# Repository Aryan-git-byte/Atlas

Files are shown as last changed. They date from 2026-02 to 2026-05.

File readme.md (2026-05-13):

# Atlas DevBoard
# Overview:
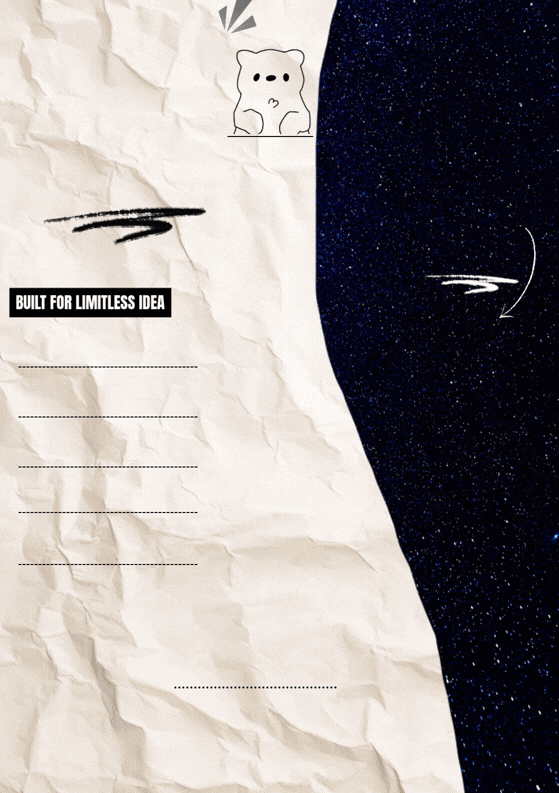
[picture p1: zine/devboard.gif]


## about the Board:
It is one of those perfect devboard i need for my projects, especically my IoTs one, and i was pretty tired of conecting different modules together, wiring em and all, SO i thought that why cant i make a board that fulfills my need, and this may even come handy for many other hackers/dev too. 
This board comprises of inbuilt BMS, GSM, GPRS, GPS, RS485 communication, mic, speaker, sd slots etc
with the main brain being esp32 s3 and A9G for gps/gprs/gsm.
## Application:
lots of IoT projects u can think of
plus normal projects too that needs lot of flash or eeprom

## How to use it:
Its pretty simple, you can just upload the code in firmawre/ through the usb connector or power it through the jst, and just upload code , interact with other modules as describe in schematic and BOOM ur powerful devboard workingggg., 
some serial cmds to test the board:

`help or ?` - show command menu   
`status` - show system info   
`reboot` - restart system   
`sd.ls` - list files  
`sd.cat` <filename> - read file   
`sd.rm` <filename> - delete file  
`gsm.at` <command> - send AT command  
`gsm.rssi` - signal strength  
`gsm.sms` <number> <message> - send SMS   
`gps.on` - enable GPS   
`gps.off` - disable GPS   
`gps.loc` - get GPS location  
`485.tx` <message> - send data    
`pin.set` <pin> <0|1> - set pin state   
`pin.get` <pin> - read pin state  
`pwr.sleep` <seconds> - light sleep   
`pwr.vbat` - read battery voltage 

# Schematic Overview:
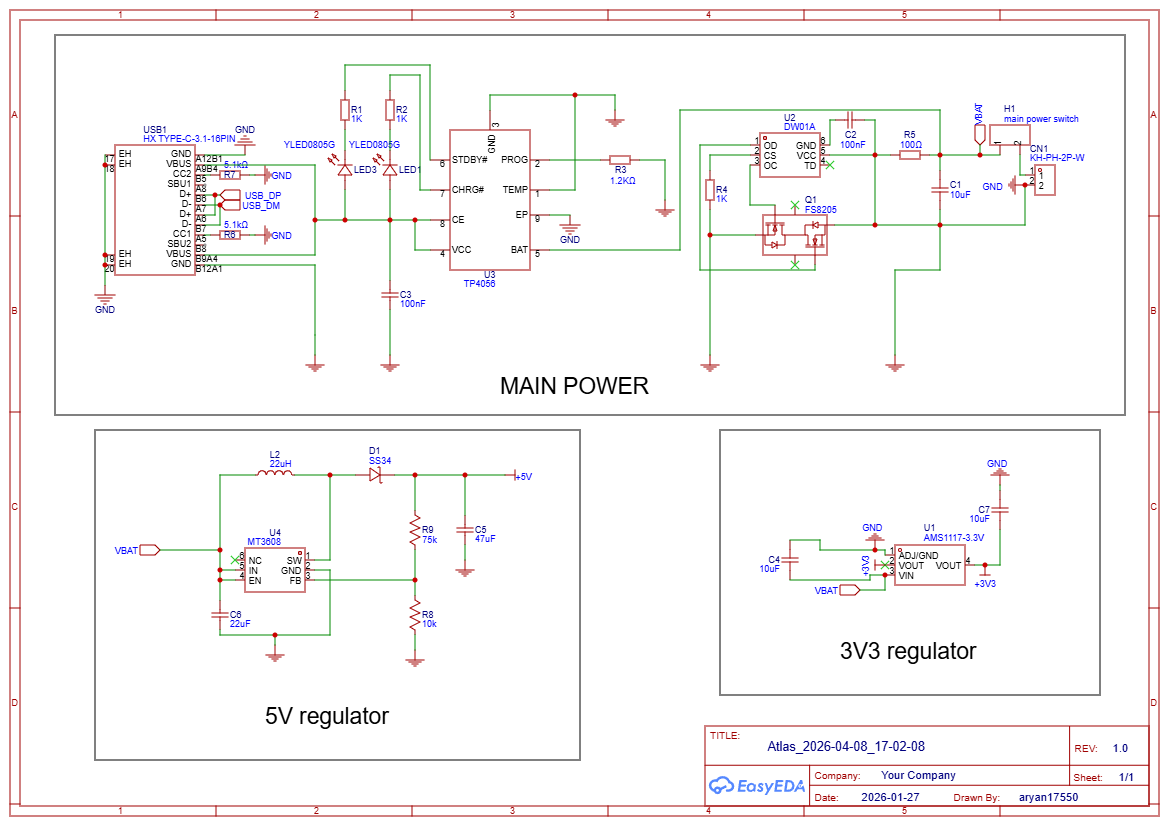
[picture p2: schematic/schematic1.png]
schematic-1

This page contains the whole power system of the board starting off we have the usb-C connector for both charging and coding, then we have BMS, a 5v Boost converter and a 3v3 linear regulator

after that we have, 
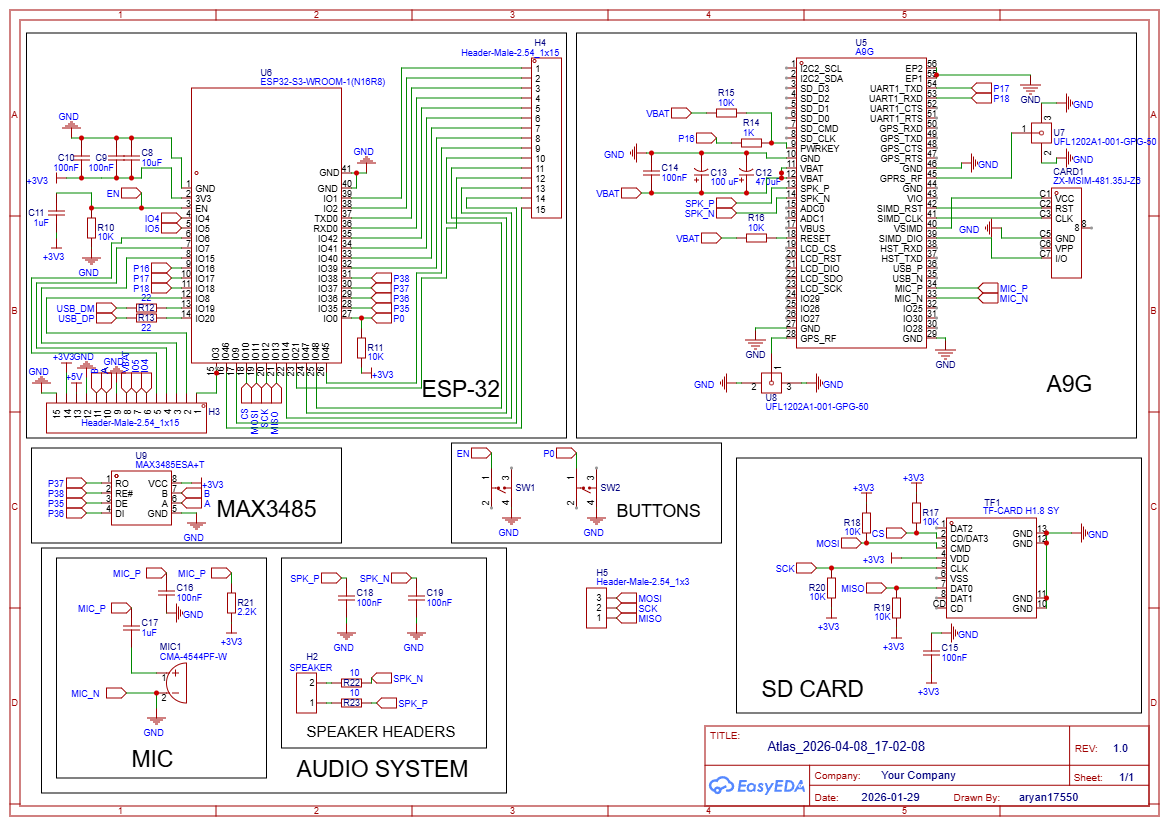
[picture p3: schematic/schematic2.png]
schematic-2

this page does the heavy work, with the first u can see the esp32-block along with its peripherals and the breakout connectors. after that we have A9G with its peripherals . and so with the max3485, buttons, jumpers, sd card, mic , speakers etc
# PCB overview:
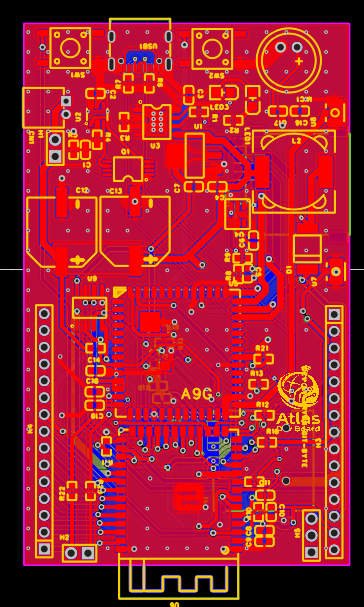
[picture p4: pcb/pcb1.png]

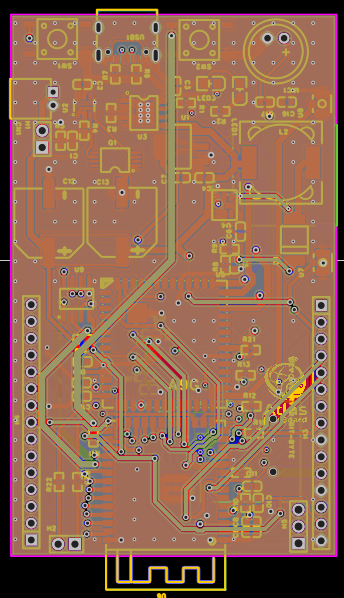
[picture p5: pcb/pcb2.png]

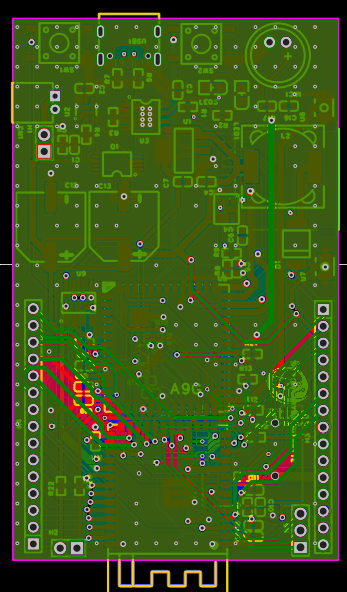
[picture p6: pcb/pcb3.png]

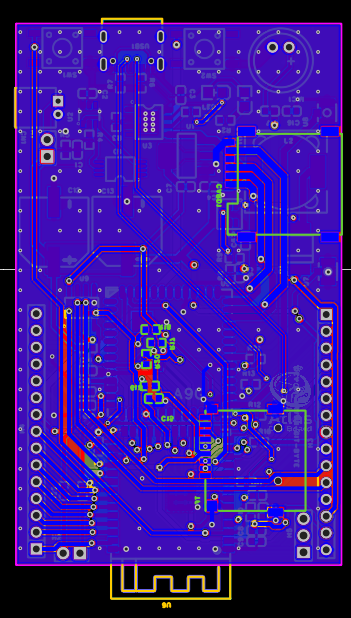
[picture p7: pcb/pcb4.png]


# BOM:
## Quartz Components/ Robu / Aero kart india:

| Item name | Quantity | Unit Cost (₹) | Link  |Total (₹) |
|---|---|---|---|---|
100 nF Capacitor 0603 (pack of 20)|1|11 rs | [link](https://quartzcomponents.com/products/kemet-100nf-50v-0603-smd-pack-x7r-multilayer-ceramic-capacitor-10-tolerence-pack-of-20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)| 11 rs
 10 uf Capacitor 0603 (pack of 20)|1|21 rs | [link](http://quartzcomponents.com/products/kemet-10uf-50v-0603-smd-pack-x5r-multilayer-ceramic-capacitor-20-tolerence-pack-of-20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)|21 rs
 1 uf Capacitor 0603 (pack of 20)|1 | 15 rs |[link](https://quartzcomponents.com/products/kemet-1uf-50v-0603-smd-pack-x5r-multilayer-ceramic-capacitor-20-tolerence-pack-of-20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)|15 rs
 470 uF electrolytic capacitor SMD | 1 | 11 rs|[link](https://quartzcomponents.com/products/470uf-16v-smd-electrolytic-capacitor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)|11 rs
 100 uF electrolytic capacitor SMD | 1 | 7 rs | [link](https://quartzcomponents.com/products/100uf-35v-smd-electrolytic-capacitor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)|7 rs
   1k resistor 0603 (pack of 20)|1|8 rs | [link](https://quartzcomponents.com/products/1k-ohm-0603-package-1-10w-smd-resistor-5-tolerance-pack-of-20-pieces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)| 8 rs
10K resistor 0603 (pack of 20)|1|9 rs |[link](https://quartzcomponents.com/products/yageo-10k-ohm-0603-package-1-10w-smd-resistor-1-tolerance-pack-of-20-pieces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)| 9 rs
1.2k resistor 0603 (pack of 20)|1|8 rs | [link](https://quartzcomponents.com/products/1-2k-ohm-0603-package-1-10w-smd-resistor-5-tolerance-pack-of-20-pieces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)|8 rs 
100Ω resistor 0603 (pack of 20)|1|9 rs | [link](http://quartzcomponents.com/products/yageo-100-ohm-0603-package-1-10w-smd-resistor-1-tolerance-pack-of-20-pieces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)|9 rs 
 5.1k resistor 0603 (pack of 20)|1|6 rs | [link](https://quartzcomponents.com/products/yageo-5-1k-ohm-0603-package-1-10w-smd-resistor-1-tolerance-pack-of-20-pieces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)| 6 rs
 75K resistor 0603 (pack of 20)|1|9 rs |[link](https://quartzcomponents.com/products/yageo-100-ohm-0603-package-1-10w-smd-resistor-1-tolerance-pack-of-20-pieces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)| 9 rs
 22Ω 0603 resistor (pack of 20)|1 | 5 rs | [link](https://quartzcomponents.com/products/yageo-22-ohm-0603-package-1-10w-smd-resistor-5-tolerance-pack-of-20-pieces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)|5 rs 
 2.2K 0603 resistor (pack of 20)|1 | 8 rs |[link](https://quartzcomponents.com/products/2-2k-ohm-0603-package-1-10w-smd-resistor-5-tolerance-pack-of-20-pieces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)| 8 rs
 10Ω 0603 resistor (pack of 20)|1 |11 rs | [link](https://quartzcomponents.com/products/yageo-10-ohm-0603-package-1-10w-smd-resistor-1-tolerance-pack-of-20-pieces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)|11 rs
 USB TYPE-C 3.1 16 PIN | 2 | 6 rs | [link](https://quartzcomponents.com/products/c-type-usb-port-plug-16-pin-smd-smt-jack-solder-connector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)| 12 rs 
 ESP32-S3-WROOM-1 N16R8 Module | 1| 367 rs | [link](https://robu.in/product/espressif-esp32-wroom-32e-n16-module/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)| 367 rs
A9G GSM/GPRS/GPS Module | 1 | 650 rs  |[link](https://aerokartindia.in/product/ai-thinker-a9g-gprs-series-module/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) | 650 rs |
AMS1117-3.3V Voltage Regulator SOT-223 | 2 | 8 rs |[link](https://quartzcomponents.com/products/ams117-3-3v-smd-voltage-regulator-3-3v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)| 16 rs 
DW01A Battery Protection IC | 2 | 4 rs | [link](https://quartzcomponents.com/products/dw01a-lithium-ion-lithium-polymer-battery-protection-ic-sot-23-6-smd-package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)| 8 rs
MT3608 Step-Up Converter | 1 | 11 rs  | [link]( https://robu.in/product/mt3608-xian-aerosemi-tech-boost-type-adjustable-2a-2v24v-sot-23-6-dc-dc-converters-rohs/ )|22 rs
FS8205A | 2 | 5 rs | [link](https://quartzcomponents.com/products/fs8205a-dual-n-channel-power-mosfet-tssop-8-package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)|10 rs
 schotkky diode | 2 | 3 rs | [link](https://quartzcomponents.com/products/ss34-3a-40v-schottky-diode-big-smd-do-214ab-smc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)|6 rs
 LED green 0805 SMD (pack of 50)|1| 20 rs |[link](https://quartzcomponents.com/products/green-led-smd-0805-package-pack-of-50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)| 20 rs 
 LED yellow 0805 SMD (pack of 50)|1| 20 rs |[link](https://quartzcomponents.com/products/yellow-led-smd-0805-package-pack-of-50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)| 20 rs 
Microphone CMA-4544PF-W | 1 | 45 rs  |[link]( https://robu.in/product/microphone-97mm-pack-of-3/) |45 rs
 2P Battery Connector 2.00mm | 1 | 13 rs | [link](https://robu.in/product/s2b-xh-alfsn-jst-1x2p-2p-xh-tin-2-25%E2%84%8385%E2%84%83-3a-1-2-5mm-brass-bend-insert-push-pullp2-5mm-wire-to-board-connector-rohs/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)|13 rs 
 Male Berg strips | 2 | 14 rs | [link](https://robu.in/product/1-month-warranty-898/)|28 rs 
Robu Shipping charges |1|50 rs||50 rs
quartz shipping charges|1|50 rs | |50 rs
aero kart india shipping charges | 1 | 125 rs ||125 rs
Tax| 1| 158.40 rs| |180.40 rs
 ## LCSC:
 | Item name | Quantity | Unit Cost (usd) | Link  |Total (usd) |
|-----------|----------|---------------|-------|---------|
47 uF 0603| 10 | 0.0627 usd | [link](https://www.lcsc.com/product-detail/C140782.html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)| 0.63 usd
22 uF 0604| 5|0.0501 usd |[link](https://www.lcsc.com/product-detail/C2762594.html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) |0.25 usd 
TP4056-42-ESOP8| 5|0.1864 usd | [link](https://www.lcsc.com/product-detail/C16581.html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)| 0.93 usd 
22 uH inductor SMD | 5 |0.1782 usd | [link](https://www.lcsc.com/product-detail/C27442.html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)| 0.89 usd
tactile switches |20|0.0322 usd | [link](https://www.lcsc.com/product-detail/C49234152.html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)|0.64 usd 
SIM card holder | 2 | 0.393 usd | [link](https://www.lcsc.com/product-detail/C7419932.html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)|0.79 usd
SD card holder|10|0.0513 usd |[link](https://www.lcsc.com/product-detail/C7529391.html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)|0.51 usd 
ufl connector | 10 | 0.0399 usd | [link](https://www.lcsc.com/product-detail/C5137195.html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)| 0.40 usd
MAX485ESA+T|2| 0.9175 usd | [link](https://www.lcsc.com/product-detail/C19738.html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)| 1.84 usd 

## Shipping bundled  with the JLCPCB order

# Total = 2167 rs (23 usd approx.)

# JLCPCB : PCB - 7 usd , (shipping charge bundled along with my USB-HUB project)
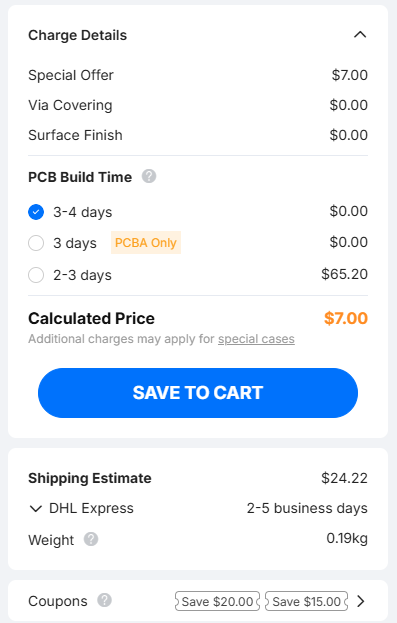
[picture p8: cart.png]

## GG, let me know if anything's left out

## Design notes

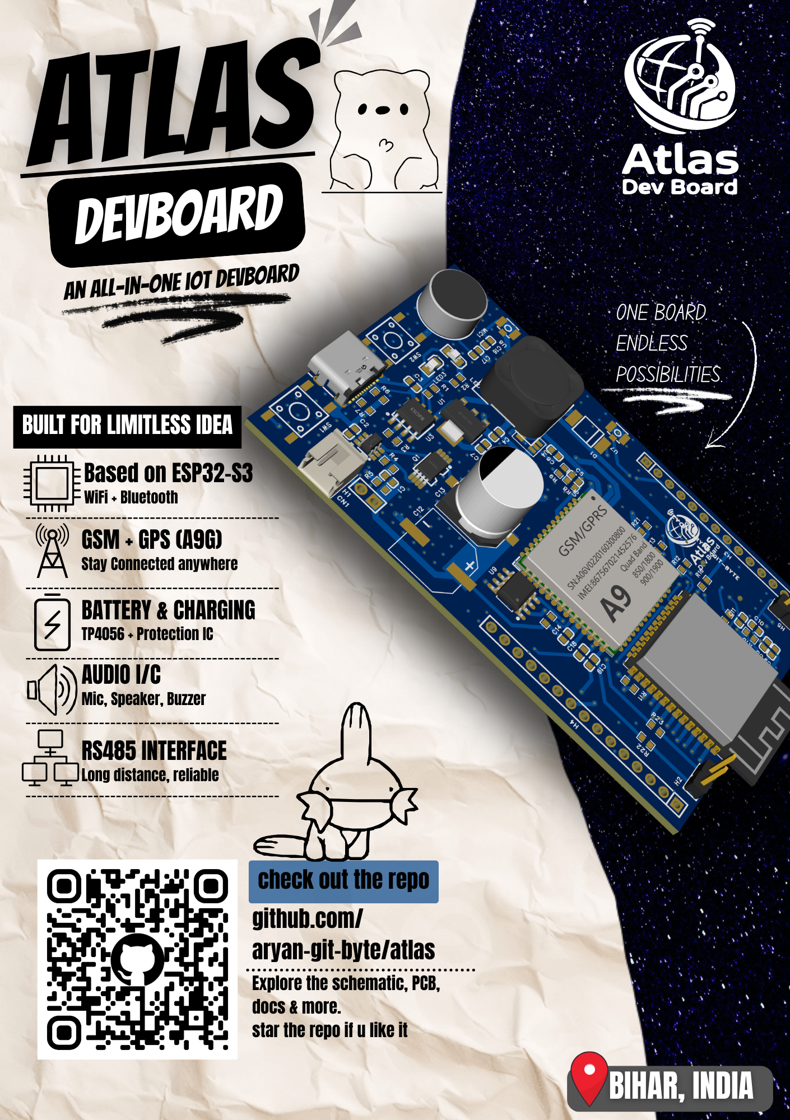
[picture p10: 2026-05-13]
zine/devboard.png

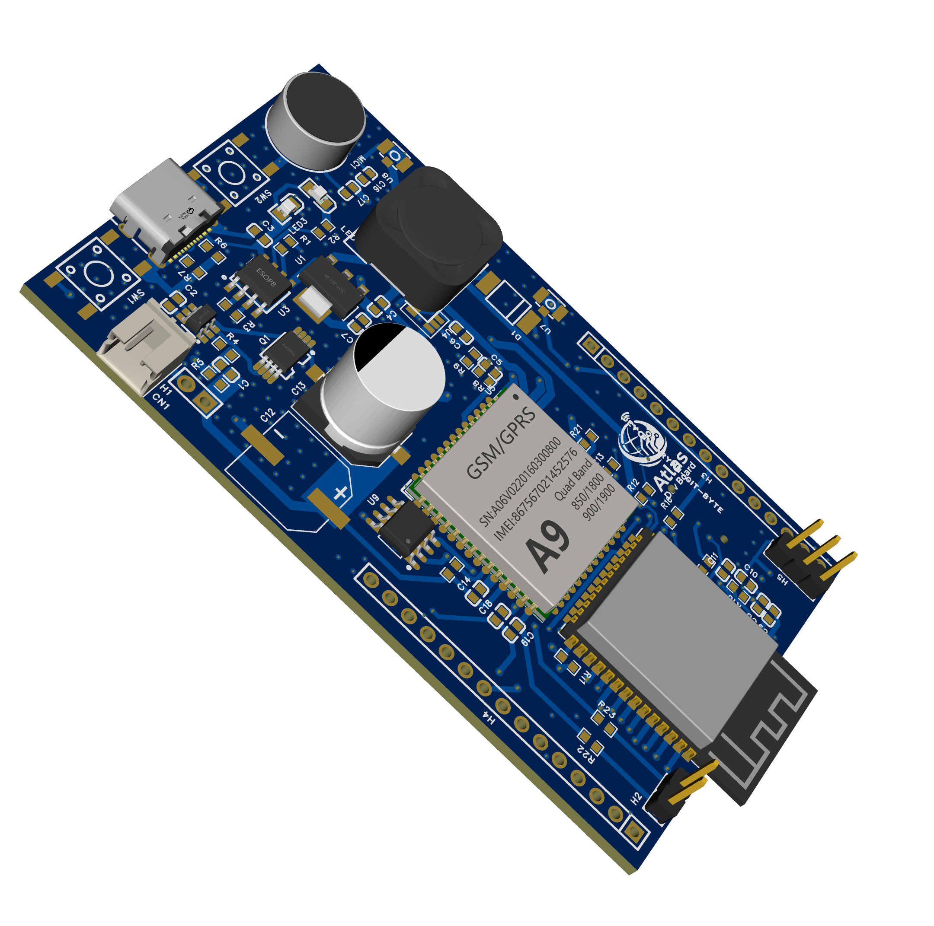
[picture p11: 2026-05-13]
zine/assets-of-zine/devboard.png

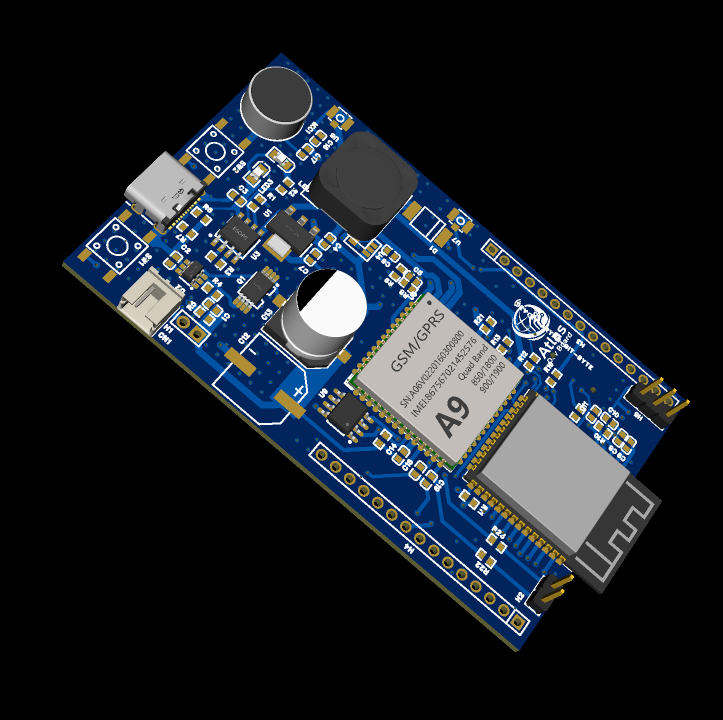
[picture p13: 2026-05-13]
3D-model/3d.png

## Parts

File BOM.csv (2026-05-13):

title | item | quantity | unit_cost_rs | unit_cost_usd | total_rs | total_usd | link
Quartz/Robu/Aero | 100 nF Capacitor 0603 (pack of 20) | 1 | 11 rs |  | 11 rs |  | https://quartzcomponents.com/products/kemet-100nf-50v-0603-smd-pack-x7r-multilayer-ceramic-capacitor-10-tolerence-pack-of-20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
Quartz/Robu/Aero | 10 uf Capacitor 0603 (pack of 20) | 1 | 21 rs |  | 21 rs |  | http://quartzcomponents.com/products/kemet-10uf-50v-0603-smd-pack-x5r-multilayer-ceramic-capacitor-20-tolerence-pack-of-20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
Quartz/Robu/Aero | 1 uf Capacitor 0603 (pack of 20) | 1 | 15 rs |  | 15 rs |  | https://quartzcomponents.com/products/kemet-1uf-50v-0603-smd-pack-x5r-multilayer-ceramic-capacitor-20-tolerence-pack-of-20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
Quartz/Robu/Aero | 470 uF electrolytic capacitor SMD | 1 | 11 rs |  | 11 rs |  | https://quartzcomponents.com/products/470uf-16v-smd-electrolytic-capacitor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
Quartz/Robu/Aero | 100 uF electrolytic capacitor SMD | 1 | 7 rs |  | 7 rs |  | https://quartzcomponents.com/products/100uf-35v-smd-electrolytic-capacitor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
Quartz/Robu/Aero | 1k resistor 0603 (pack of 20) | 1 | 8 rs |  | 8 rs |  | https://quartzcomponents.com/products/1k-ohm-0603-package-1-10w-smd-resistor-5-tolerance-pack-of-20-pieces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
Quartz/Robu/Aero | 10K resistor 0603 (pack of 20) | 1 | 9 rs |  | 9 rs |  | https://quartzcomponents.com/products/yageo-10k-ohm-0603-package-1-10w-smd-resistor-1-tolerance-pack-of-20-pieces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
Quartz/Robu/Aero | 1.2k resistor 0603 (pack of 20) | 1 | 8 rs |  | 8 rs |  | https://quartzcomponents.com/products/1-2k-ohm-0603-package-1-10w-smd-resistor-5-tolerance-pack-of-20-pieces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
Quartz/Robu/Aero | 100Ω resistor 0603 (pack of 20) | 1 | 9 rs |  | 9 rs |  | http://quartzcomponents.com/products/yageo-100-ohm-0603-package-1-10w-smd-resistor-1-tolerance-pack-of-20-pieces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
Quartz/Robu/Aero | 5.1k resistor 0603 (pack of 20) | 1 | 6 rs |  | 6 rs |  | https://quartzcomponents.com/products/yageo-5-1k-ohm-0603-package-1-10w-smd-resistor-1-tolerance-pack-of-20-pieces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
Quartz/Robu/Aero | 75K resistor 0603 (pack of 20) | 1 | 9 rs |  | 9 rs |  | https://quartzcomponents.com/products/yageo-100-ohm-0603-package-1-10w-smd-resistor-1-tolerance-pack-of-20-pieces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
Quartz/Robu/Aero | 22Ω 0603 resistor (pack of 20) | 1 | 5 rs |  | 5 rs |  | https://quartzcomponents.com/products/yageo-22-ohm-0603-package-1-10w-smd-resistor-5-tolerance-pack-of-20-pieces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
Quartz/Robu/Aero | 2.2K 0603 resistor (pack of 20) | 1 | 8 rs |  | 8 rs |  | https://quartzcomponents.com/products/2-2k-ohm-0603-package-1-10w-smd-resistor-5-tolerance-pack-of-20-pieces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
Quartz/Robu/Aero | 10Ω 0603 resistor (pack of 20) | 1 | 11 rs |  | 11 rs |  | https://quartzcomponents.com/products/yageo-10-ohm-0603-package-1-10w-smd-resistor-1-tolerance-pack-of-20-pieces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
Quartz/Robu/Aero | USB TYPE-C 3.1 16 PIN | 2 | 6 rs |  | 12 rs |  | https://quartzcomponents.com/products/c-type-usb-port-plug-16-pin-smd-smt-jack-solder-connector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
Quartz/Robu/Aero | ESP32-S3-WROOM-1 N16R8 Module | 1 | 367 rs |  | 367 rs |  | https://robu.in/product/espressif-esp32-wroom-32e-n16-module/?gad_source=1&gad_campaignid=17413441824
Quartz/Robu/Aero | A9G GSM/GPRS/GPS Module | 1 | 650 rs |  | 650 rs |  | https://aerokartindia.in/product/ai-thinker-a9g-gprs-series-module/
Quartz/Robu/Aero | AMS1117-3.3V Voltage Regulator SOT-223 | 2 | 8 rs |  | 16 rs |  | https://quartzcomponents.com/products/ams117-3-3v-smd-voltage-regulator-3-3v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
Quartz/Robu/Aero | DW01A Battery Protection IC | 2 | 4 rs |  | 8 rs |  | https://quartzcomponents.com/products/dw01a-lithium-ion-lithium-polymer-battery-protection-ic-sot-23-6-smd-package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
Quartz/Robu/Aero | MT3608 Step-Up Converter | 1 | 11 rs |  | 22 rs |  | https://robu.in/product/mt3608-xian-aerosemi-tech-boost-type-adjustable-2a-2v24v-sot-23-6-dc-dc-converters-rohs/
Quartz/Robu/Aero | FS8205A | 2 | 5 rs |  | 10 rs |  | https://quartzcomponents.com/products/fs8205a-dual-n-channel-power-mosfet-tssop-8-package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
Quartz/Robu/Aero | schotkky diode | 2 | 3 rs |  | 6 rs |  | https://quartzcomponents.com/products/ss34-3a-40v-schottky-diode-big-smd-do-214ab-smc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
Quartz/Robu/Aero | LED green 0805 SMD (pack of 50) | 1 | 20 rs |  | 20 rs |  | https://quartzcomponents.com/products/green-led-smd-0805-package-pack-of-50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
Quartz/Robu/Aero | LED yellow 0805 SMD (pack of 50) | 1 | 20 rs |  | 20 rs |  | https://quartzcomponents.com/products/yellow-led-smd-0805-package-pack-of-50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
Quartz/Robu/Aero | Microphone CMA-4544PF-W | 1 | 45 rs |  | 45 rs |  | https://robu.in/product/microphone-97mm-pack-of-3/
Quartz/Robu/Aero | 2P Battery Connector 2.00mm | 1 | 13 rs |  | 13 rs |  | https://robu.in/product/s2b-xh-alfsn-jst-1x2p-2p-xh-tin-2-25%E2%84%8385%E2%84%83-3a-1-2-5mm-brass-bend-insert-push-pullp2-5mm-wire-to-board-connector-rohs/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
Quartz/Robu/Aero | Male Berg strips | 2 | 14 rs |  | 28 rs |  | https://robu.in/product/1-month-warranty-898/
Quartz/Robu/Aero | Robu Shipping charges | 1 | 50 rs |  | 50 rs
Quartz/Robu/Aero | quartz shipping charges | 1 | 50 rs |  | 50 rs
Quartz/Robu/Aero | aero kart india shipping charges | 1 | 125 rs |  | 125 rs
Quartz/Robu/Aero | Tax | 1 | 158.40 rs |  | 180.40 rs
LCSC | 47 uF 0603 | 10 |  | 0.0627 usd |  | 0.63 usd | https://www.lcsc.com/product-detail/C140782.html
LCSC | 22 uF 0604 | 5 |  | 0.0501 usd |  | 0.25 usd | https://www.lcsc.com/product-detail/C2762594.html
LCSC | TP4056-42-ESOP8 | 5 |  | 0.1864 usd |  | 0.93 usd | https://www.lcsc.com/product-detail/C16581.html
LCSC | 22 uH inductor SMD | 5 |  | 0.1782 usd |  | 0.89 usd | https://www.lcsc.com/product-detail/C27442.html
LCSC | tactile switches | 20 |  | 0.0322 usd |  | 0.64 usd | https://www.lcsc.com/product-detail/C49234152.html
LCSC | SIM card holder | 2 |  | 0.393 usd |  | 0.79 usd | https://www.lcsc.com/product-detail/C7419932.html
LCSC | SD card holder | 10 |  | 0.0513 usd |  | 0.51 usd | https://www.lcsc.com/product-detail/C7529391.html
LCSC | ufl connector | 10 |  | 0.0399 usd |  | 0.40 usd | https://www.lcsc.com/product-detail/C5137195.html
LCSC | MAX485ESA+T | 2 |  | 0.9175 usd |  | 1.84 usd | https://www.lcsc.com/product-detail/C19738.html
Summary | Total |  |  | 2167 rs | 23 usd approx.
JLCPCB | PCB |  |  |  | 4 usd

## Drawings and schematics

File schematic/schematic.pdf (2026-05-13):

# AMS1117-3.3VVBAT

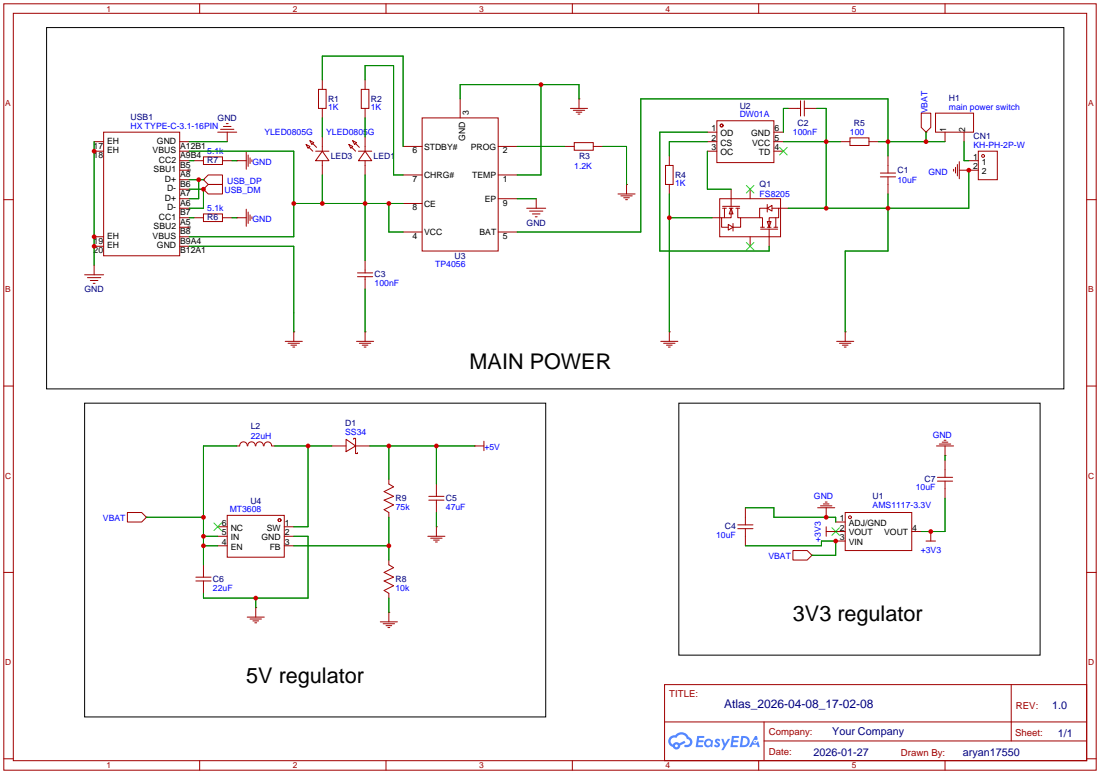
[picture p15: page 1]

IO0 27 IO35 28 IO36 29 IO37 30 IO38 31 IO39 32 IO40 33 IO41 34 IO42 35 RXD0 36 TXD0 37 IO2 38 IO1 39 GND 40

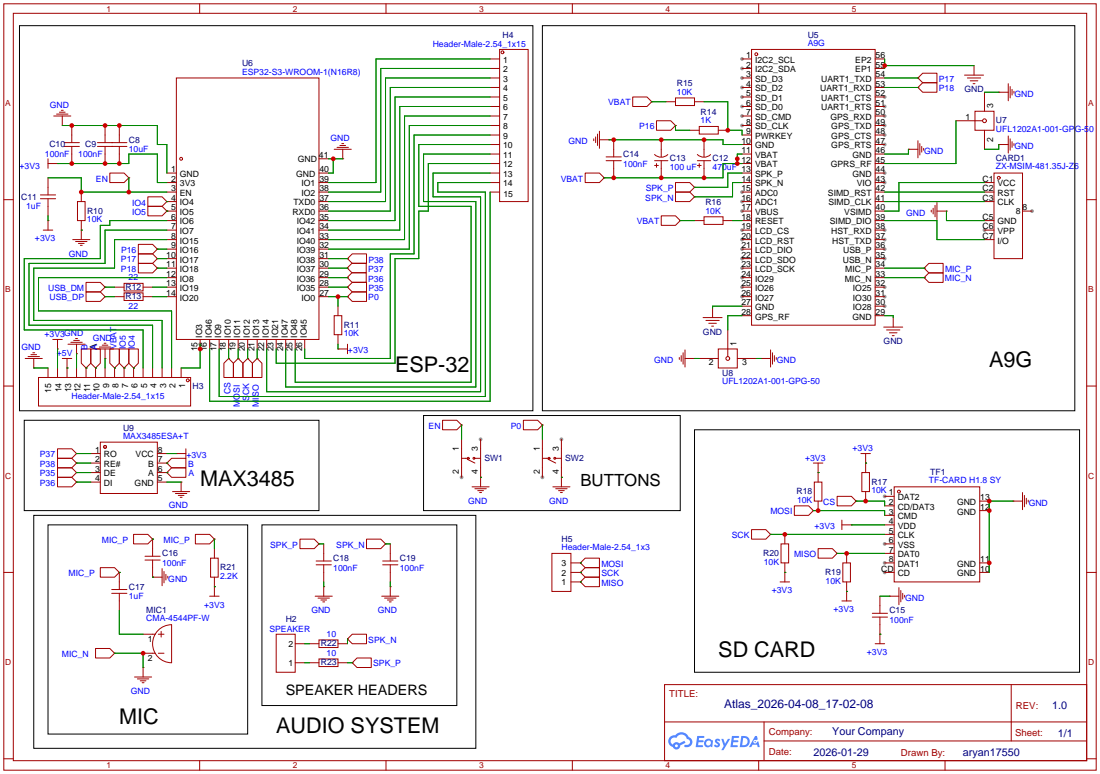
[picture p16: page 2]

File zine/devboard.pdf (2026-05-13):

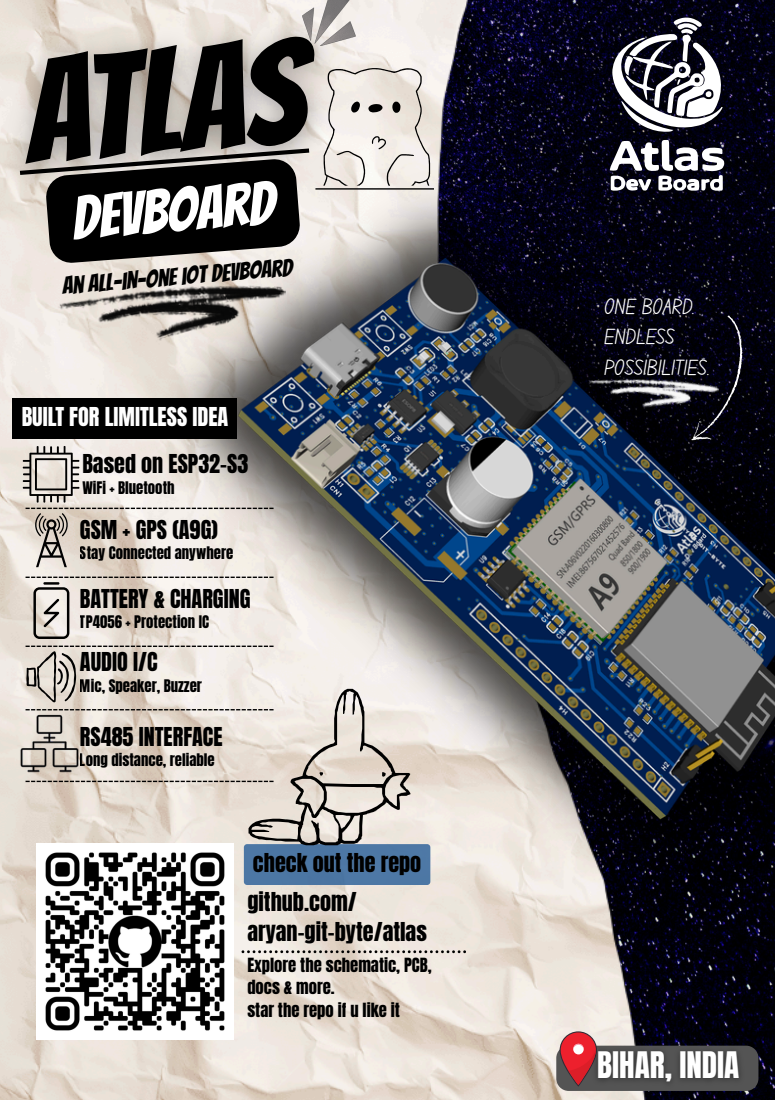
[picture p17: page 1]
ATLAS; devboard; ONE BOARD. ENDLESS POSSIBILITIES.; BIHAR, INDIA

an all-in-one iOt devboard

BUILT FOR LIMITLESS IDEA
Based on ESP32-S3
WiFi + Bluetooth
GSM + GPS (A9G)
Stay Connected anywhere
BATTERY & CHARGING
TP4056 + Protection IC
AUDIO I/C
Mic, Speaker, Buzzer
RS485 INTERFACE
Long distance, reliable

check out the repo
github.com/
aryan-git-byte/atlas
Explore the schematic, PCB,
docs & more.
star the repo if u like it

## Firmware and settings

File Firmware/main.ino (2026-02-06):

/*
 * ATLAS Development Board Firmware
 * ESP32-S3 with A9G GSM/GPS, RS485, SD Card
 */

#include <Arduino.h>
#include <Wire.h>
#include <SPI.h>
#include <SD.h>
#include <FS.h>
#include <HardwareSerial.h>

#define BOOT_BTN 0
#define STATUS_LED 2

#define SD_CS 14
#define SD_MOSI 13
#define SD_MISO 12  
#define SD_CLK 11

#define A9G_RX 18
#define A9G_TX 17
#define A9G_PWR 16
#define A9G_RST 15

#define RS485_RX 36
#define RS485_TX 37
#define RS485_DE 38
#define RS485_RE 35

#define I2C_SDA 21
#define I2C_SCL 47

#define MIC_IN 1
#define SPK_OUT 2

#define IO_4 4
#define IO_5 5
#define IO_6 6
#define IO_7 7
#define IO_8 8
#define IO_9 9
#define IO_10 10

#define SERIAL_BAUD 115200
#define A9G_BAUD 115200
#define RS485_BAUD 9600

#define A9G_CMD_TIMEOUT 8000
#define A9G_BOOT_TIME 12000
#define RS485_RESPONSE_TIME 500

#define CMD_BUF_SIZE 256
#define A9G_BUF_SIZE 512
#define RS485_BUF_SIZE 128

HardwareSerial a9gSerial(1);
HardwareSerial rs485Serial(2);

struct {
  bool sd_ok;
  bool a9g_online;
  bool rs485_init;
  bool gps_lock;
  bool gsm_reg;
  uint32_t boot_time;
  float vbat;
  int rssi;
  unsigned long last_gps_update;
} sys;

char cmd_buffer[CMD_BUF_SIZE];
int cmd_idx = 0;
unsigned long last_blink = 0;
bool led_state = false;

#define VBAT_ADC_PIN 1
#define VDIV_RATIO 3.13
#define ADC_VREF 3.3
#define ADC_RES 4095.0

void log_msg(const char* msg) {
  Serial.print("[");
  Serial.print(millis());
  Serial.print("] ");
  Serial.println(msg);
}

void log_msg(String msg) {
  log_msg(msg.c_str());
}

void blink_fast(int count) {
  for(int i = 0; i < count; i++) {
    digitalWrite(STATUS_LED, HIGH);
    delay(80);
    digitalWrite(STATUS_LED, LOW);
    delay(80);
  }
}

bool init_sdcard() {
  log_msg("SD: Starting init...");
  
  SPI.begin(SD_CLK, SD_MISO, SD_MOSI, SD_CS);
  
  if(!SD.begin(SD_CS)) {
    log_msg("SD: Mount failed");
    sys.sd_ok = false;
    return false;
  }
  
  uint8_t cardType = SD.cardType();
  if(cardType == CARD_NONE) {
    log_msg("SD: No card detected");
    sys.sd_ok = false;
    return false;
  }
  
  String type_str = (cardType == CARD_MMC) ? "MMC" : 
                    (cardType == CARD_SD) ? "SD" : 
                    (cardType == CARD_SDHC) ? "SDHC" : "???";
  log_msg("SD: Type=" + type_str);
  
  uint64_t size_mb = SD.cardSize() / (1024 * 1024);
  log_msg("SD: Size=" + String((uint32_t)size_mb) + "MB");
  
  sys.sd_ok = true;
  return true;
}

bool sd_write(const char* path, const char* data) {
  if(!sys.sd_ok) return false;
  
  File f = SD.open(path, FILE_WRITE);
  if(!f) {
    log_msg("SD: Open failed - " + String(path));
    return false;
  }
  
  size_t written = f.print(data);
  f.close();
  
  return (written > 0);
}

bool sd_append(const char* path, const char* data) {
  if(!sys.sd_ok) return false;
  
  File f = SD.open(path, FILE_APPEND);
  if(!f) return false;
  
  size_t written = f.print(data);
  f.close();
  return (written > 0);
}

String sd_read(const char* path) {
  if(!sys.sd_ok) return "";
  
  File f = SD.open(path);
  if(!f) return "";
  
  String content;
  content.reserve(f.size());
  
  while(f.available()) {
    content += (char)f.read();
  }
  f.close();
  
  return content;
}

void sd_list_dir(const char* path) {
  if(!sys.sd_ok) return;
  
  File root = SD.open(path);
  if(!root || !root.isDirectory()) {
    log_msg("SD: Invalid dir");
    return;
  }
  
  File entry = root.openNextFile();
  while(entry) {
    if(entry.isDirectory()) {
      Serial.print("  [DIR]  ");
    } else {
      Serial.print("  ");
      Serial.print(entry.size());
      Serial.print("\t");
    }
    Serial.println(entry.name());
    entry = root.openNextFile();
  }
}

String a9g_send_at(const char* cmd, uint32_t timeout = A9G_CMD_TIMEOUT) {
  a9gSerial.println(cmd);
  
  if(Serial) {
    Serial.print("A9G >> ");
    Serial.println(cmd);
  }
  
  String resp;
  resp.reserve(256);
  unsigned long start = millis();
  
  while((millis() - start) < timeout) {
    while(a9gSerial.available()) {
      char c = a9gSerial.read();
      resp += c;
      
      if(resp.endsWith("OK\r\n") || 
         resp.endsWith("ERROR\r\n") ||
         resp.endsWith("> ")) {
        goto done;
      }
    }
    delay(5);
  }
  
done:
  if(resp.length() > 0 && Serial) {
    Serial.print("A9G << ");
    Serial.println(resp);
  }
  
  return resp;
}

void a9g_power_toggle() {
  log_msg("A9G: Power cycle");
  digitalWrite(A9G_PWR, HIGH);
  delay(1200);
  digitalWrite(A9G_PWR, LOW);
  delay(A9G_BOOT_TIME);
}

bool init_a9g() {
  log_msg("A9G: Initializing...");
  
  pinMode(A9G_PWR, OUTPUT);
  digitalWrite(A9G_PWR, LOW);
  
  a9gSerial.begin(A9G_BAUD, SERIAL_8N1, A9G_RX, A9G_TX);
  delay(500);
  
  String resp = a9g_send_at("AT", 2000);
  if(resp.indexOf("OK") < 0) {
    log_msg("A9G: Not responding, power cycle");
    a9g_power_toggle();
    resp = a9g_send_at("AT", 3000);
  }
  
  if(resp.indexOf("OK") < 0) {
    log_msg("A9G: Init failed!");
    sys.a9g_online = false;
    return false;
  }
  
  a9g_send_at("ATE0");
  a9g_send_at("AT+CMGF=1");
  
  resp = a9g_send_at("AT+CREG?");
  if(resp.indexOf(",1") > 0 || resp.indexOf(",5") > 0) {
    sys.gsm_reg = true;
    log_msg("A9G: Network registered");
  } else {
    sys.gsm_reg = false;
    log_msg("A9G: Not registered (will retry later)");
  }
  
  sys.a9g_online = true;
  return true;
}

int a9g_get_rssi() {
  String resp = a9g_send_at("AT+CSQ", 3000);
  int idx = resp.indexOf("+CSQ: ");
  if(idx >= 0) {
    int comma = resp.indexOf(',', idx);
    String rssi_str = resp.substring(idx + 6, comma);
    return rssi_str.toInt();
  }
  return -1;
}

bool a9g_send_sms(const char* num, const char* msg) {
  if(!sys.a9g_online || !sys.gsm_reg) return false;
  
  String cmd = "AT+CMGS=\"";
  cmd += num;
  cmd += "\"";
  
  a9gSerial.println(cmd);
  delay(300);
  
  a9gSerial.print(msg);
  delay(100);
  a9gSerial.write(0x1A);
  
  delay(5000);
  return true;
}

void a9g_enable_gps() {
  a9g_send_at("AT+GPS=1");
  log_msg("GPS: Enabled");
}

void a9g_disable_gps() {
  a9g_send_at("AT+GPS=0");
  log_msg("GPS: Disabled");
}

String a9g_get_gps() {
  return a9g_send_at("AT+GPSRD=1");
}

void a9g_process_bg() {
  while(a9gSerial.available()) {
    String line;
    char c;
    while(a9gSerial.available() && (c = a9gSerial.read()) != '\n') {
      line += c;
    }
    
    if(line.length() > 0) {
      if(line.indexOf("+CMT:") >= 0) {
        log_msg("SMS received!");
      }
      
      if(Serial) Serial.println(line);
    }
  }
}

void rs485_mode(bool tx_enable) {
  digitalWrite(RS485_DE, tx_enable ? HIGH : LOW);
  digitalWrite(RS485_RE, tx_enable ? HIGH : LOW);
  
  if(tx_enable) {
    delayMicroseconds(50);
  }
}

bool init_rs485() {
  log_msg("RS485: Init");
  
  pinMode(RS485_DE, OUTPUT);
  pinMode(RS485_RE, OUTPUT);
  rs485_mode(false);
  
  rs485Serial.begin(RS485_BAUD, SERIAL_8N1, RS485_RX, RS485_TX);
  
  sys.rs485_init = true;
  return true;
}

void rs485_send(const char* data) {
  rs485_mode(true);
  rs485Serial.print(data);
  rs485Serial.flush();
  delayMicroseconds(100);
  rs485_mode(false);
}

void rs485_send_bytes(uint8_t* buf, size_t len) {
  rs485_mode(true);
  rs485Serial.write(buf, len);
  rs485Serial.flush();
  delayMicroseconds(100);
  rs485_mode(false);
}

String rs485_recv(uint32_t timeout = RS485_RESPONSE_TIME) {
  String data;
  unsigned long start = millis();
  
  while((millis() - start) < timeout) {
    if(rs485Serial.available()) {
      data += (char)rs485Serial.read();
    }
  }
  
  return data;
}

void rs485_process_bg() {
  if(rs485Serial.available()) {
    String msg;
    while(rs485Serial.available()) {
      msg += (char)rs485Serial.read();
      delay(2);
    }
    
    if(msg.length() > 0) {
      log_msg("RS485 RX: " + msg);
    }
  }
}

float read_battery() {
  long sum = 0;
  for(int i = 0; i < 5; i++) {
    sum += analogRead(VBAT_ADC_PIN);
    delay(5);
  }
  
  float adc_avg = sum / 5.0;
  float v = (adc_avg / ADC_RES) * ADC_VREF * VDIV_RATIO;
  
  return v;
}

void enter_light_sleep(uint32_t sec) {
  log_msg("Entering light sleep for " + String(sec) + "s");
  esp_sleep_enable_timer_wakeup(sec * 1000000ULL);
  esp_light_sleep_start();
  log_msg("Woke from sleep");
}

void print_help() {
  Serial.println("\n--- ATLAS Board Commands ---");
  Serial.println("help         - this menu");
  Serial.println("status       - system info");
  Serial.println("reboot       - restart");
  Serial.println("\nSD Card:");
  Serial.println("sd.ls        - list files");
  Serial.println("sd.cat <f>   - read file");
  Serial.println("sd.rm <f>    - delete file");
  Serial.println("\nA9G:");
  Serial.println("gsm.at <cmd> - send AT command");
  Serial.println("gsm.rssi     - signal strength");
  Serial.println("gsm.sms <num> <msg>");
  Serial.println("gps.on / gps.off");
  Serial.println("gps.loc      - get location");
  Serial.println("\nRS485:");
  Serial.println("485.tx <msg>");
  Serial.println("\nGPIO:");
  Serial.println("pin.set <n> <0|1>");
  Serial.println("pin.get <n>");
  Serial.println("\nPower:");
  Serial.println("pwr.sleep <sec>");
  Serial.println("pwr.vbat\n");
}

void print_status() {
  Serial.println("\n=== System Status ===");
  Serial.print("Uptime: ");
  Serial.print(millis() / 1000);
  Serial.println("s");
  
  Serial.print("Free RAM: ");
  Serial.print(ESP.getFreeHeap());
  Serial.println(" bytes");
  
  Serial.print("SD Card: ");
  Serial.println(sys.sd_ok ? "OK" : "FAIL");
  
  Serial.print("A9G: ");
  Serial.println(sys.a9g_online ? "Online" : "Offline");
  
  Serial.print("GSM: ");
  Serial.println(sys.gsm_reg ? "Registered" : "Not registered");
  
  Serial.print("RS485: ");
  Serial.println(sys.rs485_init ? "Ready" : "Not init");
  
  Serial.print("Battery: ");
  Serial.print(sys.vbat, 2);
  Serial.println("V");
  
  if(sys.a9g_online) {
    Serial.print("RSSI: ");
    Serial.println(sys.rssi);
  }
  
  Serial.println();
}

void handle_command(String cmd) {
  cmd.trim();
  
  if(cmd.length() == 0) return;
  
  String cmd_lower = cmd;
  cmd_lower.toLowerCase();
  
  if(cmd_lower == "help" || cmd_lower == "?") {
    print_help();
  }
  else if(cmd_lower == "status") {
    print_status();
  }
  else if(cmd_lower == "reboot") {
    Serial.println("Rebooting in 2s...");
    delay(2000);
    ESP.restart();
  }
  else if(cmd_lower == "sd.ls") {
    sd_list_dir("/");
  }
  else if(cmd_lower.startsWith("sd.cat ")) {
    String fname = cmd.substring(7);
    String content = sd_read(fname.c_str());
    Serial.println(content);
  }
  else if(cmd_lower.startsWith("sd.rm ")) {
    String fname = cmd.substring(6);
    if(SD.remove(fname.c_str())) {
      Serial.println("Deleted: " + fname);
    } else {
      Serial.println("Delete failed");
    }
  }
  else if(cmd_lower.startsWith("gsm.at ")) {
    String at = cmd.substring(7);
    a9g_send_at(at.c_str());
  }
  else if(cmd_lower == "gsm.rssi") {
    int r = a9g_get_rssi();
    Serial.print("RSSI: ");
    Serial.println(r);
  }
  else if(cmd_lower.startsWith("gsm.sms ")) {
    int sp = cmd.indexOf(' ', 8);
    if(sp > 0) {
      String num = cmd.substring(8, sp);
      String msg = cmd.substring(sp + 1);
      a9g_send_sms(num.c_str(), msg.c_str());
      Serial.println("SMS queued");
    }
  }
  else if(cmd_lower == "gps.on") {
    a9g_enable_gps();
  }
  else if(cmd_lower == "gps.off") {
    a9g_disable_gps();
  }
  else if(cmd_lower == "gps.loc") {
    String loc = a9g_get_gps();
    Serial.println(loc);
  }
  else if(cmd_lower.startsWith("485.tx ")) {
    String msg = cmd.substring(7);
    rs485_send(msg.c_str());
    Serial.println("TX: " + msg);
  }
  else if(cmd_lower.startsWith("pin.set ")) {
    int sp = cmd.indexOf(' ', 8);
    if(sp > 0) {
      int pin = cmd.substring(8, sp).toInt();
      int val = cmd.substring(sp + 1).toInt();
      pinMode(pin, OUTPUT);
      digitalWrite(pin, val);
      Serial.println("Pin " + String(pin) + " = " + String(val));
    }
  }
  else if(cmd_lower.startsWith("pin.get ")) {
    int pin = cmd.substring(8).toInt();
    pinMode(pin, INPUT);
    int val = digitalRead(pin);
    Serial.println("Pin " + String(pin) + " = " + String(val));
  }
  else if(cmd_lower.startsWith("pwr.sleep ")) {
    int sec = cmd.substring(10).toInt();
    enter_light_sleep(sec);
  }
  else if(cmd_lower == "pwr.vbat") {
    float v = read_battery();
    Serial.print("Battery: ");
    Serial.print(v, 3);
    Serial.println("V");
  }
  else {
    Serial.println("Unknown command (try 'help')");
  }
}

void process_serial_input() {
  while(Serial.available()) {
    char c = Serial.read();
    
    if(c == '\n' || c == '\r') {
      if(cmd_idx > 0) {
        cmd_buffer[cmd_idx] = 0;
        handle_command(String(cmd_buffer));
        cmd_idx = 0;
      }
    }
    else if(cmd_idx < CMD_BUF_SIZE - 1) {
      cmd_buffer[cmd_idx++] = c;
    }
  }
}

void setup() {
  Serial.begin(SERIAL_BAUD);
  delay(500);
  
  Serial.println("\n\n=================================");
  Serial.println("ATLAS Dev Board v2.1");
  Serial.println("Booting...");
  Serial.println("=================================\n");
  
  pinMode(STATUS_LED, OUTPUT);
  pinMode(BOOT_BTN, INPUT_PULLUP);
  
  digitalWrite(STATUS_LED, HIGH);
  delay(300);
  digitalWrite(STATUS_LED, LOW);
  
  Wire.begin(I2C_SDA, I2C_SCL);
  log_msg("I2C ready");
  
  init_sdcard();
  delay(200);
  
  init_a9g();
  delay(200);
  
  init_rs485();
  delay(200);
  
  sys.vbat = read_battery();
  sys.boot_time = millis();
  
  Serial.println("\n=================================");
  Serial.println("System Ready");
  Serial.println("Type 'help' for commands");
  Serial.println("=================================\n");
  
  blink_fast(2);
  
  if(sys.sd_ok) {
    String log = "\n--- Boot @ ";
    log += millis();
    log += "ms ---\n";
    log += "Heap: ";
    log += ESP.getFreeHeap();
    log += "\nVbat: ";
    log += sys.vbat;
    log += "V\n";
    sd_append("/boot.log", log.c_str());
  }
}

void loop() {
  if(millis() - last_blink > 1000) {
    last_blink = millis();
    led_state = !led_state;
    digitalWrite(STATUS_LED, led_state);
    
    sys.vbat = read_battery();
    
    if(sys.a9g_online) {
      sys.rssi = a9g_get_rssi();
    }
  }
  
  process_serial_input();
  a9g_process_bg();
  rs485_process_bg();
  
  static uint32_t btn_press_start = 0;
  static bool btn_was_pressed = false;
  
  if(digitalRead(BOOT_BTN) == LOW) {
    if(!btn_was_pressed) {
      btn_press_start = millis();
      btn_was_pressed = true;
    }
    else if((millis() - btn_press_start) > 5000) {
      Serial.println("\n*** Long press detected ***");
      blink_fast(5);
      btn_was_pressed = false;
    }
  }
  else {
    if(btn_was_pressed && (millis() - btn_press_start) < 5000) {
      Serial.println("Button pressed");
      blink_fast(1);
    }
    btn_was_pressed = false;
  }
  
  delay(10);
}

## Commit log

2026-02-07 Add BOM section with component details and links
    Added a detailed Bill of Materials (BOM) section with itemized components, quantities, and links for purchasing.
2026-05-13 completed the project
    [BOM.csv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]
